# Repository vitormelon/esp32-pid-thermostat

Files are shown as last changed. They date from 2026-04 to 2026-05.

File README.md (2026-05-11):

# ESP32 PID Thermostat

An ESP32-based temperature controller with local interface (20x4 LCD + rotary encoder) and remote control (Blynk IoT). Designed to work 100% offline — WiFi is optional and never blocks local control.

Project installed on oven

## Features

- 3 control modes: hysteresis, PID on/off, and PID time-proportional window
- Auto-tune via relay feedback (Tyreus-Luyben) for automatic PID calibration
- 10 equipment presets (Kp, Ki, Kd, window) saved to NVS
- Timer up to 24h with automatic shutdown
- Temperature graph on LCD with 7 time scales (10min to 12h)
- Power loss recovery with automatic resume
- Safety system: overtemperature, sensor failure, and stuck relay detection
- Configurable backlight timeout
- Uptime counter on home screen
- Bidirectional Blynk sync every 2s

---

## Photos

| Assembled on bench | Installed on oven | Oven overview |
|---|---|---|
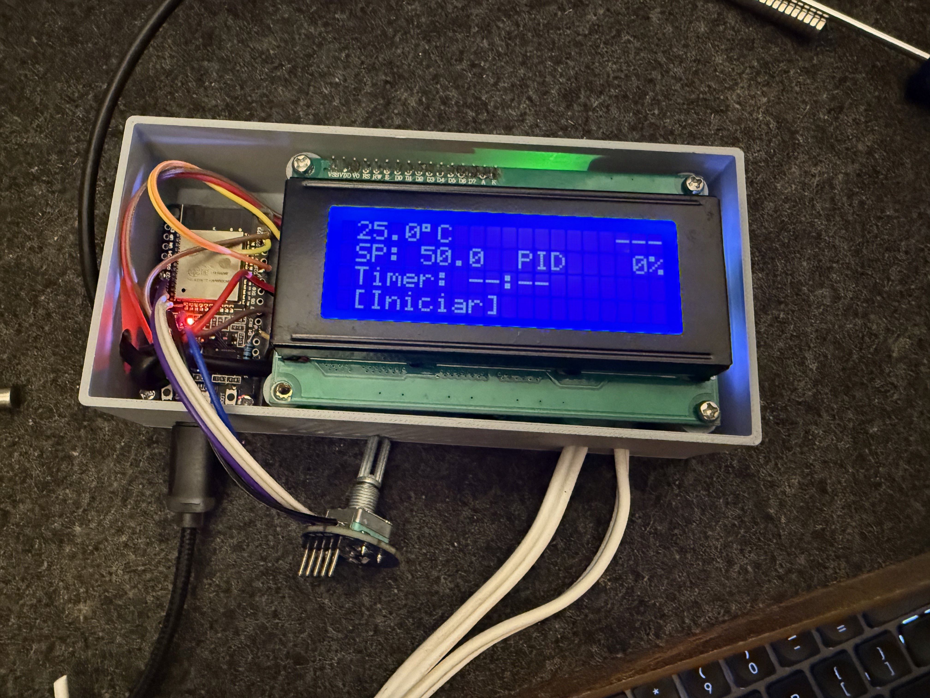
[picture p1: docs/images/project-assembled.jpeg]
Bench
|  | Oven | Overview |

---

## Bill of Materials

| Component | Description | Qty | Notes |
|---|---|---|---|
| ESP32 DevKit V1 | Microcontroller (or ESP32-S3) | 1 | Any ESP32 board with enough GPIOs |
| DS18B20 | Digital temperature sensor (OneWire, 12-bit) | 1 | Waterproof probe version recommended |
| Relay module | 1-channel, active HIGH | 1 | Rated for your heater's current |
| LCD 20x4 I2C | Character display with PCF8574 backpack | 1 | I2C address 0x27 or 0x3F |
| KY-040 | Rotary encoder with push button | 1 | 5-pin module (CLK, DT, SW, +, GND) |
| 4.7k ohm resistor | Pull-up for DS18B20 data line | 1 | 1/4W, between DATA and 3.3V |
| Jumper wires | Dupont cables for connections | ~15 | Male-to-female recommended |
| USB cable | Power and programming | 1 | Micro-USB or USB-C depending on board |
| 3D printed case | Enclosure (optional) | 1 | STL file included below |

---

## 3D Printed Case

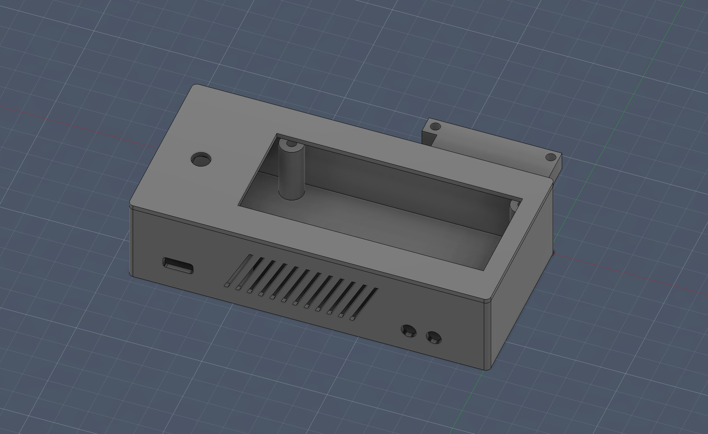
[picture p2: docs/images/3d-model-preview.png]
3D model preview


**Download:** [oven_controller_case.stl](docs/3d/oven_controller_case.stl)

Print settings: PLA, no supports, 0.2mm layer height. Has openings for LCD, encoder, USB port, and ventilation slots.

---

## Wiring

### ESP32 DevKit V1

```text
GPIO 4  ── DS18B20 DATA (4.7k pull-up to 3.3V)
GPIO 23 ── Relay IN
GPIO 21 ── LCD SDA (I2C)
GPIO 22 ── LCD SCL (I2C)
GPIO 26 ── LCD Backlight
GPIO 32 ── Encoder CLK (S1)
GPIO 33 ── Encoder DT (S2)
GPIO 25 ── Encoder SW (button)
```

### ESP32-S3

GPIOs 22-34 are not available on S3-WROOM. Use this alternative pinout:

```text
GPIO 4  ── DS18B20 DATA
GPIO 5  ── Relay IN
GPIO 8  ── LCD SDA (I2C)
GPIO 9  ── LCD SCL (I2C)
GPIO 18 ── LCD Backlight
GPIO 16 ── Encoder CLK (S1)
GPIO 17 ── Encoder DT (S2)
GPIO 15 ── Encoder SW (button)
```

All pins are configurable in `src/config.h`.

> **Important:** Power the encoder with **3.3V**, not 5V. ESP32 GPIOs are not 5V tolerant.
>
> The LCD I2C address (`LCD_ADDR`) is set to `0x3F`. If the display doesn't work, try `0x27` in `src/config.h`.

---

## Getting Started

### Prerequisites

- [PlatformIO](https://platformio.org/) (CLI or VS Code extension)
- USB cable for the ESP32

### Step by step

**1. Clone the repository**

```bash
git clone https://github.com/YOUR_USER/esp32-pid-thermostat.git
cd esp32-pid-thermostat
```

**2. Set up credentials**

Copy the example file and fill in your data:

```bash
cp include/credentials.h.example include/credentials.h
```

Edit `include/credentials.h` with your WiFi SSID, password, and Blynk tokens:

```cpp
#define WIFI_SSID       "your-wifi-ssid"
#define WIFI_PASS       "your-wifi-password"
#define BLYNK_TMPL_ID   "your-template-id"
#define BLYNK_TMPL_NAME "PID Thermostat"
#define BLYNK_TOKEN     "your-auth-token"
```

> Blynk is optional. If not configured, the system works normally offline.

**3. Adjust the board (if needed)**

`platformio.ini` is configured for `esp32dev`. For ESP32-S3, change:

```ini
board = esp32-s3-devkitc-1
```

And adjust the pins in `src/config.h` as shown above.

**4. Build**

```bash
pio run
```

**5. Upload**

```bash
pio run --target upload
```

**6. Serial monitor (optional)**

```bash
pio device monitor
```

Dependencies (Blynk, OneWire, DallasTemperature, LiquidCrystal_I2C, ESP32Encoder) are downloaded automatically by PlatformIO.

---

## Control Modes

### Hysteresis

Simple on/off control with deadband.

- T >= SetPoint → relay OFF
- T <= SetPoint - Offset → relay ON
- In between → hold current state

### PID On/Off

Full PID computation, relay switches based on threshold.

- PID output > Threshold → relay ON
- PID output <= Threshold → relay OFF
- Threshold configurable (default 50%)

### PID Window (Time-Proportional)

PID output mapped to duty cycle over time. Example: 65% output with 10s window = relay ON for 6.5s, OFF for 3.5s.

The relay only changes state when the time in the current state exceeds the PID-calculated duration. This prevents excessive switching and protects mechanical relays.

---

## Navigation (Encoder)

The encoder navigates in 3 levels:

| Action | Result |
|---|---|
| Rotate (screen level) | Switch between Home, Graph, Config, Auto-Tune |
| Click (screen level) | Enter screen items |
| Rotate (item level) | Move cursor between items |
| Click (item level) | Edit selected item |
| Rotate (edit level) | Change value |
| Click (edit level) | Confirm and return to items |
| Long press | Return to screen level. If already there, go to Home |

All menus wrap around: last item continues to first.

### Backlight

Configurable timeout: always on, 1min, 5min, or 10min. When off, any interaction first turns on the screen (without triggering actions). After 0.5s, the encoder resumes normal operation.

---

## Screens

### Home

```text
 75.3°C  01:05:30 ON
 SP: 80.0 Histerese
 Timer: 01:30
>[Iniciar]   Forno1
```

| Line | Content | Editable |
|---|---|---|
| 0 | Temperature + uptime counter + relay state | No |
| 1 | SetPoint + mode (+ PID output % if active) | SetPoint |
| 2 | Timer (`--:--` if disabled, `HH:MM:SS` countdown) | Timer HH:MM |
| 3 | Start/Stop button + active preset name | Start/Stop |

### Graph

```text
 95 -▇▅▃▂▁▁▂▃▅▇▇████
>80  ▁▂▃▅▇████████▇▅▃
 65  ▁▁▁▁▁▁▁▁▁▁▁▁▁▁▁▁
    0          [10m]
```

- 3 rows of bars (24 pixels vertical resolution)
- Left scale with `>` marking the SetPoint row
- Horizontal marker at the exact SP pixel
- Scales: 10m, 30m, 1h, 2h, 4h, 8h, 12h (saved to NVS)
- Sampled every 30s, up to 12h of history

### Settings

| Item | Visible when | Range | Step |
|---|---|---|---|
| Offset | Always | 0.5–10.0°C | 0.5 |
| Mode | Always | Hysteresis / PID On/Off / PID Window | Cycle |
| Kp | PID mode | 0–999 | 0.1 |
| Ki | PID mode | 0–999 | 0.001 |
| Kd | PID mode | 0–9999 | 1.0 |
| Window | PID Window | 2–300s | 1s |
| Threshold | PID On/Off | 10–90% | 5% |
| Backlight | Always | Always / 1min / 5min / 10min | Cycle |
| Presets | Always | Opens preset submenu | — |

Parameter changes apply with **bumpless transfer** — the loop is not reset and the relay does not jump. Encoder and Blynk paths behave identically.

| Parameter | Effect on change |
|---|---|
| Kp | Takes effect on the next compute cycle. No state changes. |
| Kd | Takes effect on the next compute cycle. No state changes. |
| Ki | Integral is rescaled so `Ki × integral` stays constant. |
| Window | Duty-cycle phase restarts; relay state is preserved. |

Mode change, preset load, and system activation still trigger a full PID reset.

### Auto-Tune (screen)

Dedicated screen (4th screen). Available only in PID modes. During execution shows temperature, SP, cycle count, ETA, previous/current cycle duration, and total elapsed time. The full algorithm is described in the [Auto-Tune](#auto-tune) section below.

### Presets

Accessible via Settings > Presets. Each preset stores Kp, Ki, Kd, and window for a specific piece of equipment. Max 10 presets with names up to 12 characters.

---

## Auto-Tune

Relay-feedback method with conservative custom constants tuned for thermal
systems with significant lag (less overshoot than classic Ziegler-Nichols).

1. Relay oscillates around SetPoint (ON below, OFF above).
2. Measures amplitude and period of each oscillation.
3. Averages Ku and Tu over 5 cycles.
4. Applies: `Kp = 0.33 Ku`, `Ki = Kp / (0.5 Tu)`, `Kd = 0.33 Kp Tu`.

These coefficients are a custom variant — Kp follows Tyreus-Luyben PI,
Ki uses the classic Ziegler-Nichols integral time, and Kd is more
generous than either to compensate for thermal-lag dominance. Multi-cycle
averaging produces more stable parameters than a single-cycle estimate.

---

## Timer

- Configurable in HH:MM on the Home screen (max 24h)
- `00:00` = no timer (runs indefinitely)
- Counts down while the system is active
- On expiry: deactivates the system and turns relay OFF
- Remaining time is preserved across power loss recovery

---

## Safety

The thresholds below are configured in `src/config.h` (`HARD_CUTOFF_TEMP`, `OVERTEMP_DELAY_MS`, `SAFETY_STUCK_DELAY_MS`, `SAFETY_STUCK_THRESHOLD`). Adjust them for your equipment.

### Hard cutoff (>= `HARD_CUTOFF_TEMP`)

Relay forced OFF immediately. The cutoff state then drives stuck-relay detection and the overtemperature timer (below).

### Stuck relay (30s after cutoff, +10°C rise)

If temperature continues to rise more than 10°C above the cutoff point within 30s of relay being commanded OFF, the firmware concludes the relay may be mechanically stuck. Toggles the GPIO 10 times rapidly to try to free the contact, then shows the error screen. **This error requires a long press to clear** (a single click would loop straight back into the same fault if the relay is still stuck).

### Overtemperature (60s above cutoff)

If temperature stays above `HARD_CUTOFF_TEMP` for `OVERTEMP_DELAY_MS` (default 60s) without triggering the stuck check, the firmware deactivates the system and shows the error screen.

### Sensor failure (no reading for 5s)

Relay OFF. System deactivated. Error screen showing last known temperature.

### Clearing safety errors

- `SENSOR_FAIL` and `OVERTEMP`: single click clears the error.
- `RELAY_STUCK`: **long press required** (see above).

### Other protections

- Safe boot: relay always starts OFF
- Watchdog: 8s timeout = automatic reset
- Non-blocking WiFi/Blynk: never interferes with local control
- Reading validation: values outside -50°C to 150°C are discarded
- Power-loss recovery prompt is non-blocking — sensor reads, WiFi, Blynk and safety checks keep running while the user decides

---

## Power Loss Recovery

If the system is active during a power outage, on reboot it shows:

```text
Ciclo interrompido!
Continuar?      18s

  [SIM]       NAO
```

- YES is pre-selected, 20s timeout = automatic resume
- Timer continues from where it stopped (does not reset)
- State saved to NVS every 30s and on every state change

---

## Blynk

Bidirectional sync every 2s. Local changes (encoder) reflect in the app and vice-versa.

| Pin | Direction | Description |
|---|---|---|
| V0 | Read | Temperature (°C) |
| V1 | Write | SetPoint (30–100°C) |
| V2 | Read | Relay (0/1) |
| V3 | Write | Offset (0.5–10°C) |
| V4 | Write | Mode (0=Hysteresis, 1=PID On/Off, 2=PID Window) |
| V5 | Write | Kp |
| V6 | Write | Ki |
| V7 | Write | Kd |
| V8 | Write | PID window (seconds) |
| V9 | Read | PID output (0–100%) |
| V11 | Write | System active (0/1) |

---

## Project Structure

```text
esp32-pid-thermostat/
├── docs/
│   ├── images/
│   │   ├── project-assembled.jpeg
│   │   ├── project-detail.jpeg
│   │   └── 3d-model-preview.png
│   └── 3d/
│       └── oven_controller_case.stl
├── include/
│   ├── credentials.h.example    ← template (tracked by git)
│   └── credentials.h            ← your real data (in .gitignore)
├── src/
│   ├── config.h                 ← pins, constants, limits
│   ├── state.h / .cpp           ← shared state between modules
│   ├── encoder.h / .cpp         ← ESP32Encoder (PCNT hardware) + button
│   ├── display.h / .cpp         ← LCD, 4 screens, graph, presets, errors
│   ├── storage.h / .cpp         ← NVS: settings, presets, recovery
│   ├── control.h / .cpp         ← PID with anti-windup, hysteresis, relay
│   ├── timer_ctrl.h / .cpp      ← countdown timer
│   ├── autotune.h / .cpp        ← relay feedback Tyreus-Luyben
│   └── main.cpp                 ← setup, loop, WiFi, Blynk, safety
├── lib/                         ← local libraries
├── platformio.ini
├── .gitignore
└── README.md
```

---

## Troubleshooting

| Problem | Solution |
|---|---|
| LCD doesn't turn on | Check 5V power to LCD. Try `LCD_ADDR` 0x27 or 0x3F |
| Encoder direction reversed | Swap `ENCODER_CLK_PIN` and `ENCODER_DT_PIN` in `config.h` |
| Encoder skips steps | Adjust `ENCODER_STEPS_PER_DETENT` (try 2 or 8) |
| Temperature shows -127 or 0 | Check 4.7k pull-up resistor and DS18B20 wiring |
| Relay doesn't switch | Verify module is active HIGH. Check pin assignment |
| WiFi won't connect | System continues offline. Check SSID/password in `credentials.h` |
| Credentials compile error | Copy `credentials.h.example` to `credentials.h` |
| ESP keeps resetting | Check watchdog (8s). Look at serial for `Guru Meditation Error` |
| `Invalid pin selected` | GPIOs 22-34 don't exist on ESP32-S3. Adjust `config.h` |

---

## License

MIT

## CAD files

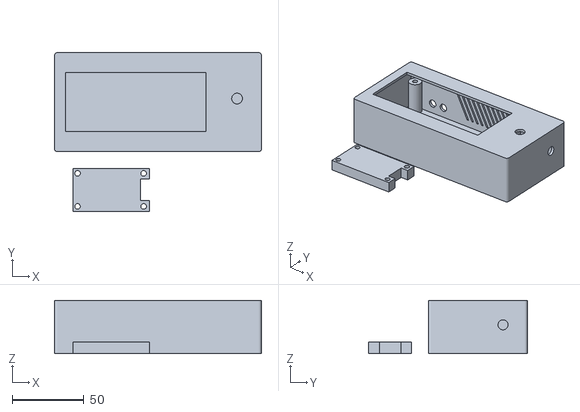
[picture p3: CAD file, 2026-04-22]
docs/3d/oven_controller_case.stl
144.0 x 110.5 x 37.0

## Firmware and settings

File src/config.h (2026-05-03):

#pragma once
#include <Arduino.h>

// ============================================================
// PIN DEFINITIONS
// ============================================================
#define SENSOR_PIN          4
#define RELAY_PIN           23
#define LCD_BACKLIGHT_PIN   26
#define ENCODER_CLK_PIN     32
#define ENCODER_DT_PIN      33
#define ENCODER_SW_PIN      25
// I2C usa pinos padrão: SDA=21, SCL=22

// ============================================================
// LCD
// ============================================================
#define LCD_ADDR            0x3F
#define LCD_COLS            20
#define LCD_ROWS            4
// Frequência do barramento I2C. 100kHz é seguro para qualquer fiação.
// 400kHz funciona com fios curtos (<10cm) e bons pull-ups (4.7kΩ externos).
// Se a tela exibir lixo após mudança, reduza para 100000UL.
#define I2C_FREQ_HZ         100000UL

// ============================================================
// TEMPERATURE
// ============================================================
#define TEMP_READ_INTERVAL      2000UL
#define TEMP_CONVERSION_DELAY   800UL
#define SENSOR_FAIL_TIMEOUT     5000UL
#define HARD_CUTOFF_TEMP        115.0f
#define CUTOFF_RECOVERY_TEMP    105.0f
#define OVERTEMP_DELAY_MS       60000UL
#define TEMP_MIN_VALID          -50.0f
#define TEMP_MAX_VALID          150.0f

// ============================================================
// CONTROL DEFAULTS & LIMITS
// ============================================================
#define DEFAULT_SETPOINT        80.0f
#define DEFAULT_OFFSET          2.0f
#define SP_MIN                  30.0f
#define SP_MAX                  100.0f
#define SP_STEP                 1.0f
#define OFFSET_MIN              0.5f
#define OFFSET_MAX              10.0f
#define OFFSET_STEP             0.5f

#define MODE_HYSTERESIS         0
#define MODE_PID_ONOFF          1
#define MODE_PID_WINDOW         2
#define NUM_MODES               3

// ============================================================
// PID DEFAULTS & LIMITS
// ============================================================
#define DEFAULT_PID_KP          2.0f
#define DEFAULT_PID_KI          0.01f
#define DEFAULT_PID_KD          50.0f
#define DEFAULT_PID_WINDOW_MS   10000UL
#define DEFAULT_PID_THRESHOLD   50.0f

#define PID_KP_MIN              0.0f
#define PID_KP_MAX              999.0f
#define PID_KP_STEP             0.1f
#define PID_KI_MIN              0.0f
#define PID_KI_MAX              999.0f
#define PID_KI_STEP             0.001f
#define PID_KD_MIN              0.0f
#define PID_KD_MAX              9999.0f
#define PID_KD_STEP             1.0f
#define PID_WINDOW_MIN_S        2
#define PID_WINDOW_MAX_S        300
#define PID_WINDOW_STEP_S       1
#define PID_THRESHOLD_MIN       10.0f
#define PID_THRESHOLD_MAX       90.0f
#define PID_THRESHOLD_STEP      5.0f

// ============================================================
// ENCODER
// ============================================================
#define LONG_PRESS_MS           1000UL
#define BL_WAKE_DELAY_MS        100UL
// Aumentado de 4ms para 20ms: encoders mecânicos baratos podem fazer
// bounce de 5-15ms. Latência percebida não muda (ainda <1 frame de UI).
#define ENCODER_DEBOUNCE_MS     20
#define ENCODER_CLICK_MS        5
#define ENCODER_STEPS_PER_DETENT 4

// ============================================================
// BACKLIGHT
// ============================================================
#define BL_TIMEOUT_COUNT        4
static const unsigned long BL_TIMEOUTS[] = {0, 60000, 300000, 600000};
static const char* const BL_TIMEOUT_NAMES[] = {"Sempre", "1 min", "5 min", "10 min"};

// ============================================================
// WIFI
// ============================================================
#define WIFI_CONNECT_TIMEOUT    15000UL
#define WIFI_RETRY_PAUSE        5000UL
#define WIFI_RETRY_CYCLE_PAUSE  30000UL
#define WIFI_MAX_RETRIES        5
#define WIFI_OFFLINE_RESTART_TIME 300000UL

// ============================================================
// BLYNK
// ============================================================
#define BLYNK_SEND_INTERVAL     2000UL
// Tempo máximo que Blynk.connect() bloqueia o loop. Reduzido de 3s para
// 1s para minimizar latência percebida em outras tarefas (sensor, encoder,
// safety). Trade-off: conexões em redes lentas podem precisar de mais retries.
#define BLYNK_CONNECT_TIMEOUT_MS 1000UL
// Backoff exponencial entre tentativas: começa em 15s, dobra até 5min.
// Reseta para o mínimo quando reconecta.
#define BLYNK_RETRY_INTERVAL_MIN 15000UL
#define BLYNK_RETRY_INTERVAL_MAX 300000UL

// ============================================================
// WATCHDOG
// ============================================================
#define WDT_TIMEOUT_SEC         8

// ============================================================
// RECOVERY
// ============================================================
#define RECOVERY_TIMEOUT_MS     20000UL
#define RECOVERY_SAVE_INTERVAL  30000UL

// ============================================================
// PRESETS
// ============================================================
#define MAX_PRESETS              10
#define PRESET_NAME_MAX_LEN     12

// ============================================================
// GRAPH
// ============================================================
#define GRAPH_DATA_COLS         16
#define GRAPH_DATA_ROWS         3
#define GRAPH_MAX_HISTORY       1440
#define GRAPH_SAMPLE_INTERVAL   30000UL
#define GRAPH_SCALE_COUNT       7
static const unsigned long GRAPH_SCALE_SECS[] = {600, 1800, 3600, 7200, 14400, 28800, 43200};
static const char* const GRAPH_SCALE_NAMES[] = {"10m","30m","1h","2h","4h","8h","12h"};

// ============================================================
// TIMER
// ============================================================
#define MAX_TIMER_MINUTES       1440

// ============================================================
// AUTOTUNE
// ============================================================
#define AUTOTUNE_CYCLES         5

// ============================================================
// SAFETY
// ============================================================
#define SAFETY_STUCK_THRESHOLD  10.0f
#define SAFETY_STUCK_DELAY_MS   30000UL
#define SAFETY_UNSTICK_CYCLES   10

// ============================================================
// DISPLAY
// ============================================================
#define DISPLAY_UPDATE_MS       50UL
#define BLINK_INTERVAL_MS       500UL

// Charset para edição de nomes de presets
#define CHARSET_STR "ABCDEFGHIJKLMNOPQRSTUVWXYZ0123456789 "
#define CHARSET_LEN 37

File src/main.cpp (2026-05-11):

// ============================================================
// ESP32 PID THERMOSTAT
// Controle de temperatura com LCD 20x4 + Rotary Encoder
// Arquitetura: modular, não bloqueante, tolerante a falhas
// ============================================================

#include "credentials.h"

#define BLYNK_TEMPLATE_ID   BLYNK_TMPL_ID
#define BLYNK_TEMPLATE_NAME BLYNK_TMPL_NAME
#define BLYNK_AUTH_TOKEN    BLYNK_TOKEN

#include <Arduino.h>
#include <WiFi.h>
#include <BlynkSimpleEsp32.h>
#include <OneWire.h>
#include <DallasTemperature.h>
#include <esp_task_wdt.h>

#include "config.h"
#include "state.h"
#include "encoder.h"
#include "display.h"
#include "storage.h"
#include "control.h"
#include "timer_ctrl.h"
#include "autotune.h"
#include "safety.h"

// --- Sensor ---
static OneWire oneWire(SENSOR_PIN);
static DallasTemperature sensors(&oneWire);

// --- Temperatura (estado interno) ---
enum TempState { TEMP_IDLE, TEMP_CONVERTING };
static TempState     tempState        = TEMP_IDLE;
static unsigned long tempConvStart    = 0;
static unsigned long lastTempRead     = 0;

// --- WiFi (estado interno) ---
enum WiFiSt { WF_INIT, WF_CONNECTING, WF_CONNECTED, WF_RETRY_WAIT, WF_FAILED };
static WiFiSt        wfState          = WF_INIT;
static int           wfRetryCount     = 0;
static unsigned long wfStateTime      = 0;

// --- Blynk ---
static bool          blynkConfigured    = false;
static unsigned long lastBlynkRetry     = 0;
static unsigned long lastBlynkSend      = 0;
static unsigned long blynkRetryInterval = BLYNK_RETRY_INTERVAL_MIN;

// --- Backlight ---
static bool          blOn             = true;
static unsigned long lastInteraction  = 0;
static bool          wakeDelay        = false;
static unsigned long wakeDelayStart   = 0;

// --- Recovery ---
static unsigned long lastRecoverySave = 0;

// ============================================================
// TEMPERATURA (DS18B20)
// ============================================================
static void initSensor() {
    sensors.begin();
    sensors.setResolution(12);
    sensors.setWaitForConversion(false);
    Serial.println("[TEMP] DS18B20 init (12-bit, non-blocking)");
}

static void manageTemperature() {
    switch (tempState) {
        case TEMP_IDLE:
            if (millis() - lastTempRead >= TEMP_READ_INTERVAL) {
                sensors.requestTemperatures();
                tempConvStart = millis();
                tempState = TEMP_CONVERTING;
            }
            break;

        case TEMP_CONVERTING:
            if (millis() - tempConvStart >= TEMP_CONVERSION_DELAY) {
                float t = sensors.getTempCByIndex(0);
                lastTempRead = millis();
                tempState = TEMP_IDLE;

                bool valid = !isnan(t)
                          && t != DEVICE_DISCONNECTED_C
                          && t > TEMP_MIN_VALID
                          && t < TEMP_MAX_VALID;

                if (!valid) {
                    Serial.printf("[TEMP] Leitura invalida: %.2f\n", t);
                    if (firstValidReading &&
                        millis() - lastValidTempTime >= SENSOR_FAIL_TIMEOUT) {
                        if (!sensorFailed) {
                            sensorFailed = true;
                            setRelay(false);
                            Serial.println("[SEG] Sensor falhou >5s — rele OFF");
                        }
                    }
                } else {
                    currentTemp     = t;
                    lastValidTempTime = millis();
                    sensorFailed    = false;
                    newTempReading  = true;

                    if (!firstValidReading) {
                        firstValidReading = true;
                        Serial.printf("[TEMP] Primeira leitura: %.2f%cC\n", t, 0xB0);
                    }
                    Serial.printf("[TEMP] %.2f%cC\n", t, 0xB0);
                }
            }
            break;
    }
}

// ============================================================
// SEGURANÇA — cleanup orquestrado quando safety dispara
// ============================================================
static void tryUnstickRelay() {
    Serial.println("[SEG] Tentando desgrudar rele...");
    for (int i = 0; i < SAFETY_UNSTICK_CYCLES; i++) {
        digitalWrite(RELAY_PIN, HIGH);
        delay(50);
        digitalWrite(RELAY_PIN, LOW);
        delay(50);
        esp_task_wdt_reset();
    }
    relayState = false;
    Serial.println("[SEG] Rele toggled. Desligado.");
}

static void onSafetyTrigger(SafetyError err, float trigTemp) {
    if (autotuneIsRunning()) autotuneCancel();
    displayResetAutotuneUI();
    timerStop();
    if (err == SAFETY_RELAY_STUCK) tryUnstickRelay();
    storageSaveRecoveryState();
    Serial.printf("[SEG] ERRO %d! Trigger=%.1f Atual=%.1f\n",
                  err, trigTemp, currentTemp);
}

// ============================================================
// WIFI (não bloqueante, SEM restart automático)
// ============================================================
static void manageWiFi() {
    switch (wfState) {
        case WF_INIT:
            Serial.println("[WIFI] Iniciando...");
            WiFi.mode(WIFI_STA);
            WiFi.setAutoReconnect(true);
            WiFi.begin(WIFI_SSID, WIFI_PASS);
            wfRetryCount = 0;
            wfStateTime  = millis();
            wfState      = WF_CONNECTING;
            break;

        case WF_CONNECTING:
            if (WiFi.status() == WL_CONNECTED) {
                Serial.printf("[WIFI] Conectado! IP: %s\n",
                              WiFi.localIP().toString().c_str());
                wfState       = WF_CONNECTED;
                wifiConnected = true;
            } else if (millis() - wfStateTime >= WIFI_CONNECT_TIMEOUT) {
                wfRetryCount++;
                Serial.printf("[WIFI] Tentativa %d/%d falhou\n",
                              wfRetryCount, WIFI_MAX_RETRIES);
                if (wfRetryCount >= WIFI_MAX_RETRIES) {
                    wfState     = WF_FAILED;
                    wfStateTime = millis();
                    Serial.println("[WIFI] Tentativas esgotadas — continuando offline");
                } else {
                    WiFi.disconnect();
                    wfState     = WF_RETRY_WAIT;
                    wfStateTime = millis();
                }
            }
            break;

        case WF_CONNECTED:
            if (WiFi.status() != WL_CONNECTED) {
                Serial.println("[WIFI] Desconectado!");
                wifiConnected = false;
                wfState       = WF_INIT;
            }
            break;

        case WF_RETRY_WAIT:
            if (millis() - wfStateTime >= WIFI_RETRY_PAUSE) {
                WiFi.begin(WIFI_SSID, WIFI_PASS);
                wfStateTime = millis();
                wfState     = WF_CONNECTING;
            }
            break;

        case WF_FAILED:
            wifiConnected = false;
            if (millis() - wfStateTime >= WIFI_RETRY_CYCLE_PAUSE) {
                wfRetryCount = 0;
                wfState      = WF_INIT;
            }
            break;
    }
}

// ============================================================
// BLYNK
// ============================================================
static void sendBlynkData() {
    if (!Blynk.connected()) return;
    if (millis() - lastBlynkSend < BLYNK_SEND_INTERVAL) return;
    lastBlynkSend = millis();
    Blynk.virtualWrite(V0,  currentTemp);
    Blynk.virtualWrite(V1,  setPoint);
    Blynk.virtualWrite(V2,  relayState ? 1 : 0);
    Blynk.virtualWrite(V3,  offset);
    Blynk.virtualWrite(V4,  controlMode);
    Blynk.virtualWrite(V5,  pidKp);
    Blynk.virtualWrite(V6,  pidKi);
    Blynk.virtualWrite(V7,  pidKd);
    Blynk.virtualWrite(V8,  (int)(pidWindowSize / 1000));
    Blynk.virtualWrite(V9,  pidOutput);
    Blynk.virtualWrite(V11, systemActive ? 1 : 0);
}

static void manageBlynk() {
    if (WiFi.status() != WL_CONNECTED) {
        // Reset backoff: assim que WiFi voltar, primeira tentativa é rápida.
        blynkRetryInterval = BLYNK_RETRY_INTERVAL_MIN;
        return;
    }

    if (!blynkConfigured) {
        Blynk.config(BLYNK_AUTH_TOKEN);
        blynkConfigured = true;
    }

    if (!Blynk.connected()) {
        if (millis() - lastBlynkRetry >= blynkRetryInterval) {
            Serial.printf("[BLYNK] Tentando conectar... (proxima retry em %lus)\n",
                          blynkRetryInterval / 1000);
            Blynk.connect(BLYNK_CONNECT_TIMEOUT_MS);
            lastBlynkRetry = millis();
            // Backoff exponencial: dobra até o máximo
            unsigned long next = blynkRetryInterval * 2;
            blynkRetryInterval = (next > BLYNK_RETRY_INTERVAL_MAX)
                                  ? BLYNK_RETRY_INTERVAL_MAX
                                  : next;
        }
    } else {
        blynkConnected     = true;
        blynkRetryInterval = BLYNK_RETRY_INTERVAL_MIN;  // reset enquanto conectado
        Blynk.run();
        sendBlynkData();
    }
}

// --- Blynk Callbacks ---

BLYNK_CONNECTED() {
    Serial.println("[BLYNK] Conectado — sync");
    Blynk.virtualWrite(V0,  currentTemp);
    Blynk.virtualWrite(V1,  setPoint);
    Blynk.virtualWrite(V2,  relayState ? 1 : 0);
    Blynk.virtualWrite(V3,  offset);
    Blynk.virtualWrite(V4,  controlMode);
    Blynk.virtualWrite(V5,  pidKp);
    Blynk.virtualWrite(V6,  pidKi);
    Blynk.virtualWrite(V7,  pidKd);
    Blynk.virtualWrite(V8,  (int)(pidWindowSize / 1000));
    Blynk.virtualWrite(V9,  pidOutput);
    Blynk.virtualWrite(V11, systemActive ? 1 : 0);
}

BLYNK_WRITE(V1) {
    float v = param.asFloat();
    if (v >= SP_MIN && v <= SP_MAX) {
        setPoint = v;
        storageSaveSetPoint();
        Serial.printf("[BLYNK] SP=%.1f\n", setPoint);
    }
}

BLYNK_WRITE(V3) {
    float v = param.asFloat();
    if (v >= OFFSET_MIN && v <= OFFSET_MAX) {
        offset = v;
        storageSaveOffset();
        Serial.printf("[BLYNK] Off=%.1f\n", offset);
    }
}

BLYNK_WRITE(V4) {
    int v = param.asInt();
    if (v >= 0 && v < NUM_MODES) {
        controlMode = v;
        storageSaveControlMode();
        controlReset();
        Serial.printf("[BLYNK] Mode=%d\n", controlMode);
    }
}

BLYNK_WRITE(V5) {
    float v = param.asFloat();
    if (v >= PID_KP_MIN && v <= PID_KP_MAX) {
        pidKp = v;                  // bumpless: Kp applies directly, no reset
        storageSavePidKp();
        Serial.printf("[BLYNK] Kp=%.3f\n", pidKp);
    }
}

BLYNK_WRITE(V6) {
    float v = param.asFloat();
    if (v >= PID_KI_MIN && v <= PID_KI_MAX) {
        float oldKi = pidKi;
        pidKi = v;
        controlReparamKi(oldKi);    // preserves Ki * integral
        storageSavePidKi();
        Serial.printf("[BLYNK] Ki=%.4f\n", pidKi);
    }
}

BLYNK_WRITE(V7) {
    float v = param.asFloat();
    if (v >= PID_KD_MIN && v <= PID_KD_MAX) {
        pidKd = v;                  // bumpless: Kd applies directly, no reset
        storageSavePidKd();
        Serial.printf("[BLYNK] Kd=%.1f\n", pidKd);
    }
}

BLYNK_WRITE(V8) {
    unsigned long ms = (unsigned long)(param.asInt()) * 1000UL;
    if (ms >= (unsigned long)PID_WINDOW_MIN_S * 1000UL &&
        ms <= (unsigned long)PID_WINDOW_MAX_S * 1000UL) {
        pidWindowSize = ms;
        controlReparamWindow();     // restart only the duty-cycle phase
        storageSavePidWindow();
        Serial.printf("[BLYNK] Win=%lums\n", pidWindowSize);
    }
}

BLYNK_WRITE(V11) {
    bool v = param.asInt() != 0;
    if (v != systemActive) {
        systemActive = v;
        if (systemActive) {
            systemStartMs = millis();
            controlReset();
            if (timerSetMinutes > 0) timerStart();
        } else {
            setRelay(false);
            timerStop();
        }
        storageSaveRecoveryState();
        Serial.printf("[BLYNK] Active=%d\n", systemActive);
    }
}

// ============================================================
// BACKLIGHT + INPUT
// ============================================================
static void handleInputAndBacklight() {
    EncoderInput in = encoderRead();
    bool any = (in.delta != 0 || in.pressed || in.longPress);

    if (any) lastInteraction = millis();

    // Backlight auto-off
    unsigned long timeout = BL_TIMEOUTS[backlightTimeoutIndex];
    if (timeout > 0 && blOn && millis() - lastInteraction >= timeout) {
        displaySetBacklight(false);
        displayResetNavToScreen();
        blOn = false;
    }

    if (!any) return;

    // Wake backlight
    if (!blOn) {
        displaySetBacklight(true);
        blOn = true;
        wakeDelay = true;
        wakeDelayStart = millis();
        return;
    }

    // Ignore input during wake delay
    if (wakeDelay) {
        if (millis() - wakeDelayStart < BL_WAKE_DELAY_MS) return;
        wakeDelay = false;
    }

    displayHandleInput(in);
}

// ============================================================
// RECOVERY SAVE
// ============================================================
static void manageRecoverySave() {
    if (millis() - lastRecoverySave < RECOVERY_SAVE_INTERVAL) return;
    lastRecoverySave = millis();
    storageSaveRecoveryState();
}

// ============================================================
// RECOVERY APPLY (não bloqueante)
// ============================================================
static void applyRecovery(bool resume) {
    if (resume) {
        systemActive    = true;
        timerSetMinutes = recoveryTimerSet;
        if (recoveryTimerSet > 0 && recoveryTimerRem > 0) {
            timerResumeFromRecovery(recoveryTimerRem);
        }
        controlReset();
        systemStartMs = millis();
        Serial.println("[RECOVERY] Ciclo retomado");
    } else {
        Serial.println("[RECOVERY] Ciclo descartado");
    }
    storageClearRecoveryState();
    recoveryReset();
}

static void manageRecovery() {
    if (!recoveryPending) return;
    if (recoveryDecisionMade) {
        applyRecovery(recoveryDecisionResume);
        return;
    }
    if (millis() - recoveryStartMs >= RECOVERY_TIMEOUT_MS) {
        applyRecovery(true);  // timeout → SIM por padrão
    }
}

// ============================================================
// FREERTOS TASKS
// ============================================================
// Arquitetura:
//   - appTask     (Core 1, prio 5):  controle, safety, timer, recovery
//   - displayTask (Core 1, prio 2):  encoder + UI rendering
//   - networkTask (Core 0, prio 1):  WiFi + Blynk (pode bloquear sem afetar)
//
// Loop principal Arduino vira no-op. Cada task é watchdogged.
// State global é compartilhado; mudanças críticas no relé estão protegidas
// por critical section em setRelay/setRelayForce. Demais escritas dependem
// de atomicidade single-word do ESP32 (int/float/bool — alinhados são atomic).

static TaskHandle_t hAppTask     = NULL;
static TaskHandle_t hDisplayTask = NULL;
static TaskHandle_t hNetworkTask = NULL;

static void appTask(void* /*arg*/) {
    esp_task_wdt_add(NULL);
    while (true) {
        manageTemperature();
        safetyCheck();

        AutotuneState atSt = autotuneGetState();
        if (atSt == AT_HEATING || atSt == AT_COOLING) {
            autotuneUpdate();
        } else if (atSt == AT_DONE) {
            setRelay(false);
        } else if (!recoveryPending) {
            controlRun();
        }

        if (systemActive) timerUpdate();
        if (timerIsExpired()) {
            systemActive = false;
            setRelay(false);
            storageSaveRecoveryState();
            Serial.println("[TIMER] Sistema desativado por timer");
        }

        manageRecovery();
        manageRecoverySave();

        esp_task_wdt_reset();
        vTaskDelay(pdMS_TO_TICKS(20));   // 50Hz tick — control loop
    }
}

static void displayTask(void* /*arg*/) {
    esp_task_wdt_add(NULL);
    while (true) {
        handleInputAndBacklight();
        displayUpdate();
        displayGraphSample();

        esp_task_wdt_reset();
        vTaskDelay(pdMS_TO_TICKS(20));   // 50Hz tick — UI fluida
    }
}

static void networkTask(void* /*arg*/) {
    esp_task_wdt_add(NULL);
    while (true) {
        manageWiFi();
        manageBlynk();

        esp_task_wdt_reset();
        vTaskDelay(pdMS_TO_TICKS(50));   // 20Hz — rede sem urgência
    }
}

// Loga o "high water mark" (menor stack livre) de cada task.
// Útil pra dimensionar stack — chame após o sistema rodar um pouco.
static void logStackHighWaterMarks() {
    if (hAppTask)     Serial.printf("[STACK] app:     %u bytes livres\n",
                                    uxTaskGetStackHighWaterMark(hAppTask));
    if (hDisplayTask) Serial.printf("[STACK] display: %u bytes livres\n",
                                    uxTaskGetStackHighWaterMark(hDisplayTask));
    if (hNetworkTask) Serial.printf("[STACK] network: %u bytes livres\n",
                                    uxTaskGetStackHighWaterMark(hNetworkTask));
}

// ============================================================
// SETUP
// ============================================================
void setup() {
    Serial.begin(115200);
    Serial.println();
    Serial.println("========================================");
    Serial.println("  ESP32 PID THERMOSTAT");
    Serial.println("========================================");

    // 1. Relê OFF (boot seguro)
    pinMode(RELAY_PIN, OUTPUT);
    digitalWrite(RELAY_PIN, LOW);
    relayState = false;
    Serial.println("[BOOT] Rele OFF");

    // 2. Watchdog (cada task se registra; loop principal não está sob WDT)
    esp_task_wdt_init(WDT_TIMEOUT_SEC, true);
    Serial.printf("[BOOT] WDT %ds\n", WDT_TIMEOUT_SEC);

    // 3. Carregar configurações
    storageLoadSettings();
    storageLoadPresets();

    // 4. Sensor
    initSensor();

    // 5. Encoder
    encoderInit();

    // 6. LCD
    displayInit();

    // 7. Timer
    timerInit();

    // 8. Controle
    controlInit();
    safetyInit();
    safetySetTriggerCallback(onSafetyTrigger);

    // 9. Recovery check (não bloqueante: tela e decisão acontecem no loop)
    if (storageHasRecoveryState()) {
        storageLoadRecoveryState(recoveryTimerRem, recoveryTimerSet);
        recoveryPending        = true;
        recoveryStartMs        = millis();
        recoveryChoice         = true;
        recoveryDecisionMade   = false;
        recoveryDecisionResume = true;
        Serial.printf("[RECOVERY] Pendente — timerSet=%u min, trem=%lu ms\n",
                      recoveryTimerSet, recoveryTimerRem);
    }

    // 10. WiFi deferred
    wfState = WF_INIT;
    lastInteraction = millis();

    // 11. Cria as 3 tasks. Stacks generosos (4kB control/display, 8kB network
    //     porque WiFi+Blynk consomem mais). Cada task se registra no WDT.
    xTaskCreatePinnedToCore(appTask,     "app",     4096, NULL, 5, &hAppTask,     APP_CPU_NUM);
    xTaskCreatePinnedToCore(displayTask, "display", 4096, NULL, 2, &hDisplayTask, APP_CPU_NUM);
    xTaskCreatePinnedToCore(networkTask, "network", 8192, NULL, 1, &hNetworkTask, PRO_CPU_NUM);

    Serial.println("[BOOT] Tasks criadas (app/display em Core 1, network em Core 0)");
    Serial.println("[BOOT] Setup completo");
    Serial.println("========================================");
}

// ============================================================
// LOOP PRINCIPAL — vazio. Toda lógica está nas tasks.
// O loopTask do Arduino fica suspended via vTaskDelay longo.
// A cada 30s, loga o stack high-water-mark das tasks (debug de dimensionamento).
// ============================================================
void loop() {
    static unsigned long lastStackLog = 0;
    if (millis() - lastStackLog >= 30000UL) {
        lastStackLog = millis();
        logStackHighWaterMarks();
    }
    vTaskDelay(pdMS_TO_TICKS(1000));
}

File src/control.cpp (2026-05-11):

#include "control.h"
#include "state.h"
#include "config.h"

// Lock crítico para mudanças no estado do relé. setRelay/setRelayForce podem
// ser chamados de múltiplas tasks (control loop, display input, network).
// Em ESP32: portMUX_TYPE (spinlock leve, atomic entre cores).
// No host (testes): no-op.
#ifdef ARDUINO_ARCH_ESP32
  #include "freertos/FreeRTOS.h"
  static portMUX_TYPE relayMux    = portMUX_INITIALIZER_UNLOCKED;
  static portMUX_TYPE pidStateMux = portMUX_INITIALIZER_UNLOCKED;
  #define RELAY_LOCK()    portENTER_CRITICAL(&relayMux)
  #define RELAY_UNLOCK()  portEXIT_CRITICAL(&relayMux)
  // Protects pidIntegral / relayPhaseStart / lastRelayForPhase against
  // concurrent access by the control task (computePID, controlPIDWindow)
  // and external mutators (controlReparamKi/Window from encoder or Blynk
  // tasks). Lock order: PID_LOCK never wraps RELAY_LOCK or vice-versa.
  #define PID_LOCK()      portENTER_CRITICAL(&pidStateMux)
  #define PID_UNLOCK()    portEXIT_CRITICAL(&pidStateMux)
#else
  #define RELAY_LOCK()    ((void)0)
  #define RELAY_UNLOCK()  ((void)0)
  #define PID_LOCK()      ((void)0)
  #define PID_UNLOCK()    ((void)0)
#endif

static float pidIntegral      = 0.0f;
static float pidLastError     = 0.0f;
static float pidFilteredDeriv = 0.0f;
static unsigned long lastPIDCompute    = 0;
static unsigned long relayPhaseStart   = 0;
static bool          lastRelayForPhase = false;

static const float DERIV_FILTER_ALPHA = 0.3f;

void controlInit() {
    pidIntegral      = 0.0f;
    pidLastError     = 0.0f;
    pidFilteredDeriv = 0.0f;
    pidOutput        = 0.0f;
    lastPIDCompute    = millis();
    relayPhaseStart   = millis();
    lastRelayForPhase = false;
}

void controlReset() {
    controlInit();
}

// Bumpless transfer on Ki change: keeps (Ki * integral) constant so the
// output does not jump. Reapplies the integral clamp to the new Ki bound.
// PID_LOCK serializes the read-modify-write against the control task.
void controlReparamKi(float oldKi) {
    PID_LOCK();
    if (pidKi <= 0.0f) {
        pidIntegral = 0.0f;
    } else {
        if (oldKi > 0.0f && oldKi != pidKi) {
            pidIntegral *= oldKi / pidKi;
        }
        float maxInt = 50.0f / pidKi;
        pidIntegral = constrain(pidIntegral, -maxInt, maxInt);
    }
    PID_UNLOCK();
}

// Window size changed: discard the current phase and restart the duty
// countdown in the current relay state (does not touch the GPIO).
// PID_LOCK serializes against controlPIDWindow in the control task.
void controlReparamWindow() {
    PID_LOCK();
    relayPhaseStart   = millis();
    lastRelayForPhase = relayState;
    PID_UNLOCK();
}

void setRelay(bool on) {
    bool changed;
    RELAY_LOCK();
    changed = (relayState != on);
    if (changed) {
        relayState = on;
        digitalWrite(RELAY_PIN, on ? HIGH : LOW);
    }
    RELAY_UNLOCK();
    if (changed) Serial.printf("[RELAY] %s\n", on ? "LIGADO" : "DESLIGADO");
}

// Em paths de segurança queremos garantir o estado físico do GPIO
// mesmo que o software ache que já está correto.
void setRelayForce(bool on) {
    RELAY_LOCK();
    relayState = on;
    digitalWrite(RELAY_PIN, on ? HIGH : LOW);
    RELAY_UNLOCK();
}

// --- Histerese simples ---
static void controlHysteresis() {
    if (currentTemp >= setPoint) {
        setRelay(false);
    } else if (currentTemp <= setPoint - offset) {
        setRelay(true);
    }
}

// --- PID: calcula output 0-100% ---
static void computePID() {
    if (!newTempReading) return;

    unsigned long now = millis();
    float dt = (now - lastPIDCompute) / 1000.0f;
    dt = constrain(dt, 0.001f, 10.0f);

    float error = setPoint - currentTemp;

    float rawDeriv = (error - pidLastError) / dt;
    pidFilteredDeriv = DERIV_FILTER_ALPHA * rawDeriv
                     + (1.0f - DERIV_FILTER_ALPHA) * pidFilteredDeriv;

    PID_LOCK();
    if (pidKi <= 0.0f) {
        pidIntegral = 0.0f;
    } else {
        bool satHigh = (pidOutput >= 100.0f);
        bool satLow  = (pidOutput <= 0.0f);
        if ((!satHigh && !satLow) ||
            (satHigh && error < 0.0f) ||
            (satLow  && error > 0.0f)) {
            pidIntegral += error * dt;
        }

        float maxInt = 50.0f / pidKi;
        pidIntegral = constrain(pidIntegral, -maxInt, maxInt);
    }
    float integralSnapshot = pidIntegral;
    PID_UNLOCK();

    pidOutput = constrain(
        pidKp * error + pidKi * integralSnapshot + pidKd * pidFilteredDeriv,
        0.0f, 100.0f
    );

    pidLastError   = error;
    lastPIDCompute = now;
}

// --- PID On/Off: liga se output > threshold ---
static void controlPIDOnOff() {
    computePID();
    setRelay(pidOutput > pidThreshold);
}
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

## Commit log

2026-04-22 Initial release: ESP32 PID Thermostat
    Full-featured temperature controller with:
    - 3 control modes (hysteresis, PID on/off, PID time-proportional window)
    - Auto-tune via relay feedback (Tyreus-Luyben)
    - 10 equipment presets saved to NVS
    - 24h timer with auto-shutdown
    - Temperature graph on LCD (7 time scales, 12h history)
    - Power loss recovery with automatic resume
    - Safety system (overtemp, sensor fail, stuck relay detection)
    - Blynk IoT remote control
    - 3D printable case (STL included)
    [oven_controller_case.stl]
2026-04-25 Add native tests, CI, safety module, and bug fixes (#1)
    * Add native tests, CI, safety module, and bug fixes
    Bug fixes:
    - #1 controlRun no longer runs during autotune AT_DONE (relay stays OFF
    until user accepts/rejects); add autotuneReset() to return to AT_IDLE
    - #2 safety: stuck-relay check (30s) now runs BEFORE overtemp (60s);
    set HARD_CUTOFF_TEMP=30, CUTOFF_RECOVERY_TEMP=25, OVERTEMP_DELAY_MS=60s
    - #3+#4 displayResetAutotuneUI() called on safety trigger; displayUpdate
    now handles AT_CANCELLED/AT_IDLE in NAV_AUTOTUNE_RUN
    - #5 PID anti-windup: pidIntegral forced to 0 when Ki=0 (no silent windup)
    - #6 storageSaveRecoveryState() called when timer expires
    - #7 recovery screen is non-blo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
    [autotune.cpp, config.h, control.cpp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]
2026-04-25 Second-pass bug fixes (TDD) + dead code removal
    Bug C — remove dead code:
    - Drop addToMovingAverage/getMovingAverage/movingAvgBuffer from control
    (declared and populated but never consumed by any control logic)
    - Drop AUTOTUNE_NOISE_BAND from config.h (defined, never referenced)
    - Drop MOVING_AVG_SAMPLES from config.h
    Bug F — applyRecovery() leaks stale state:
    - Add recoveryReset() in state.{h,cpp} that zeroes all 7 recovery globals
    to defaults, not just recoveryPending/DecisionMade
    - main.cpp::applyRecovery() now calls recoveryReset() at the end
    Bug I — storageSaveGraphScale() didn't validate input:
    - Now constrains scale to [0, GRAPH_SCALE_COUNT-1] before writing NVS
    - Previous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
    [autotune.cpp, config.h, control.cpp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]
2026-04-25 docs: update Safety section to reflect new thresholds and clear gestures
    - HARD_CUTOFF defaults to 30°C (configurable in config.h), not 100°C
    - Stuck check runs at 30s BEFORE overtemp (60s), not after
    - RELAY_STUCK requires long press to clear (single click was looping)
    - Mention non-blocking recovery prompt and Blynk
2026-04-26 perf: diff redraw + encoder ISR + FreeRTOS tasks
    Three independent improvements that compound to make the system feel
    significantly more responsive (UI, encoder click, control loop).
    ## 1. Display: diff redraw + I2C clock config
    src/display.{cpp,h}, lib/native_mocks/{LiquidCrystal_I2C,Wire}.{h,cpp}
    - Add 4×20-char screen buffer; lcdFlush only writes characters that
    changed since last frame, in contiguous runs (one setCursor per run)
    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
2026-04-26 ux: preset name editor — character no longer blinks
    The blinking character at the cursor position made it hard to read what
    was being edited (the char disappeared every 500ms). Replaced with a
    static character — the ^ marker on the line below already indicates
    position unambiguously.
    The previous logic that overrode the editing slot with '_' on alternate
    blink frames was removed. Unfilled positions still show '_' as a "empty
    slot" hint.
    Long-press behavior in NAV_CHAR_EDIT is unchanged (still cancels).
    With the more responsive encoder click, navigating positions is fast
    enough that no shortcut to [OK] is needed.
    [display.cpp]
2026-05-02 fix(safety): restore HARD_CUTOFF_TEMP above SP_MAX
    HARD_CUTOFF_TEMP/CUTOFF_RECOVERY_TEMP were lowered to 30/25 in commit
    75adab1 for bench testing and never reverted. With SP=80C, the relay
    shut off at 30C and SAFETY_OVERTEMP fired ~60s later at ~31-32C, so
    the oven was unusable above bench-test temperatures.
    Raised cutoff to 115C with 105C recovery: 15C of headroom above SP_MAX
    (100C) for PID overshoot, 10C of hysteresis to avoid chattering.
    Added two regression tests under BUG #I:
    - A static invariant guarding HARD_CUTOFF_TEMP > SP_MAX with >=10C
    headroom, so the bench-test override can't silently come back.
    - A behavioral test simulating a normal warmup ramp from 25C to 75C
    with SP=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
    [config.h, test_regressions.cpp]
2026-05-11 feat(control): bumpless transfer for Kp/Ki/Kd/Window changes
    Tunable-parameter handlers no longer call controlReset(), which used to
    zero the integral and restart the relay phase — causing a disruptive
    transient (~5°C undershoot in field tests) every time the user adjusted
    a knob mid-operation.
    New APIs in control.cpp:
    - controlReparamKi(oldKi): rescales the integral so Ki * integral stays
    constant, preserving the steady-state contribution.
    - controlReparamWindow(): restarts only the duty-cycle phase, keeping
    the relay state intact.
    Encoder (display.cpp) and Blynk (main.cpp) paths route Kp/Ki/Kd/Window
    changes through these APIs instead of controlReset(). Mode change,
    preset load, a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
    [control.cpp, display.cpp, main.cpp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]
